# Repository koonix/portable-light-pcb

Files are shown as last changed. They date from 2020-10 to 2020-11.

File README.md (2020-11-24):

# Portable Light

This circuit is used in a battery-powered portable handy light source,
consisting of an array of LEDs, powered by a Panasonic lithium battery.

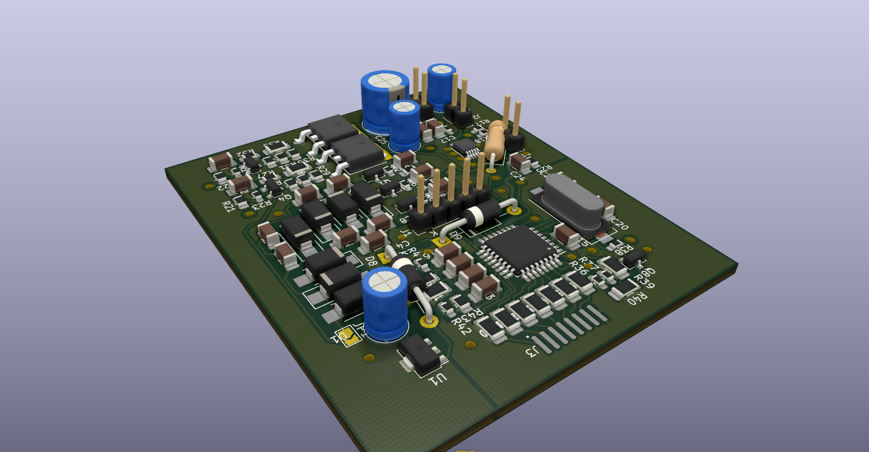
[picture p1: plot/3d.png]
3D Model of the old single-pcb version


## Modules

This circuit can be divided into these modules:

* [Control](#control-module)
* [Buck Converter](#buck-converter-module)
* [Charge Pump](#charge-pump-module)
* [Battery Charger](#battery-charger-module)

### Control Module

This module consists of the following:

* Microcontroller and it's driving components
* Shift register chip for driving the 7-Segment
* A 7-Segment and it's accompanying components

### Buck Converter Module

This module steps down the battery's voltage down to 3 Volts which is suitable
for the LEDs.

If battery voltage drops below 3 Volts however, this module is
turned off and the battery's voltage is directly passed through to the LEDs.

The signals required for control of the buck converter are provided by
the microcontroller.

### Charge Pump Module

The Control and Buck Converter modules require voltages upwards of 5 Volts
for their function, mainly needed by MOSFET's gates or the microcontroller
(When operating near 20MHz).

For that reason, this module consists of a 'Dickson charge pump' that converts
the 2.5v ~ 4.2v of the battery to 8v ~ 15v.

The signals required for driving the charge pump are provided by
the microcontroller.

### Battery Charger Module

Consisting of a LTC1733 Single-Cell Lithium Charge Controller, this module
takes care of topping off the battery when a charger is connected.

## More Detail

### How the 7-Segment is controlled/driven

A single CD4094 Shift-and-Store Register chip (similar to the infamous 595
Shift Register), Takes CLOCK, DATA, STROBE and OUTPUT-ENABLE signals from
the microcontroller and outputs the signals needed for controlling
the 7-Segment.

These signals are connected to bases of 7 PNP Transistors which drive the
LEDs of the 7-Segment directly.

### Control Module's input power

Taking advantage of two schottky diodes, power to the control
module will get sourced from either the battery or the charge pump (Which is
regulated down to 5 Volts.).

Because of the redundant-psu style dual-diode circuit, current will get sourced
from whichever source providing a higher voltage.

The diode accross Vout and Vin of the regulator is there to protect
the regulator if the Vout of the regulator goes higher than the Vin.
This shouldn't be much of a problem because of relatively small leakage
current of the dual-diode circuit, but is put there *'Just-in-Case™'*.

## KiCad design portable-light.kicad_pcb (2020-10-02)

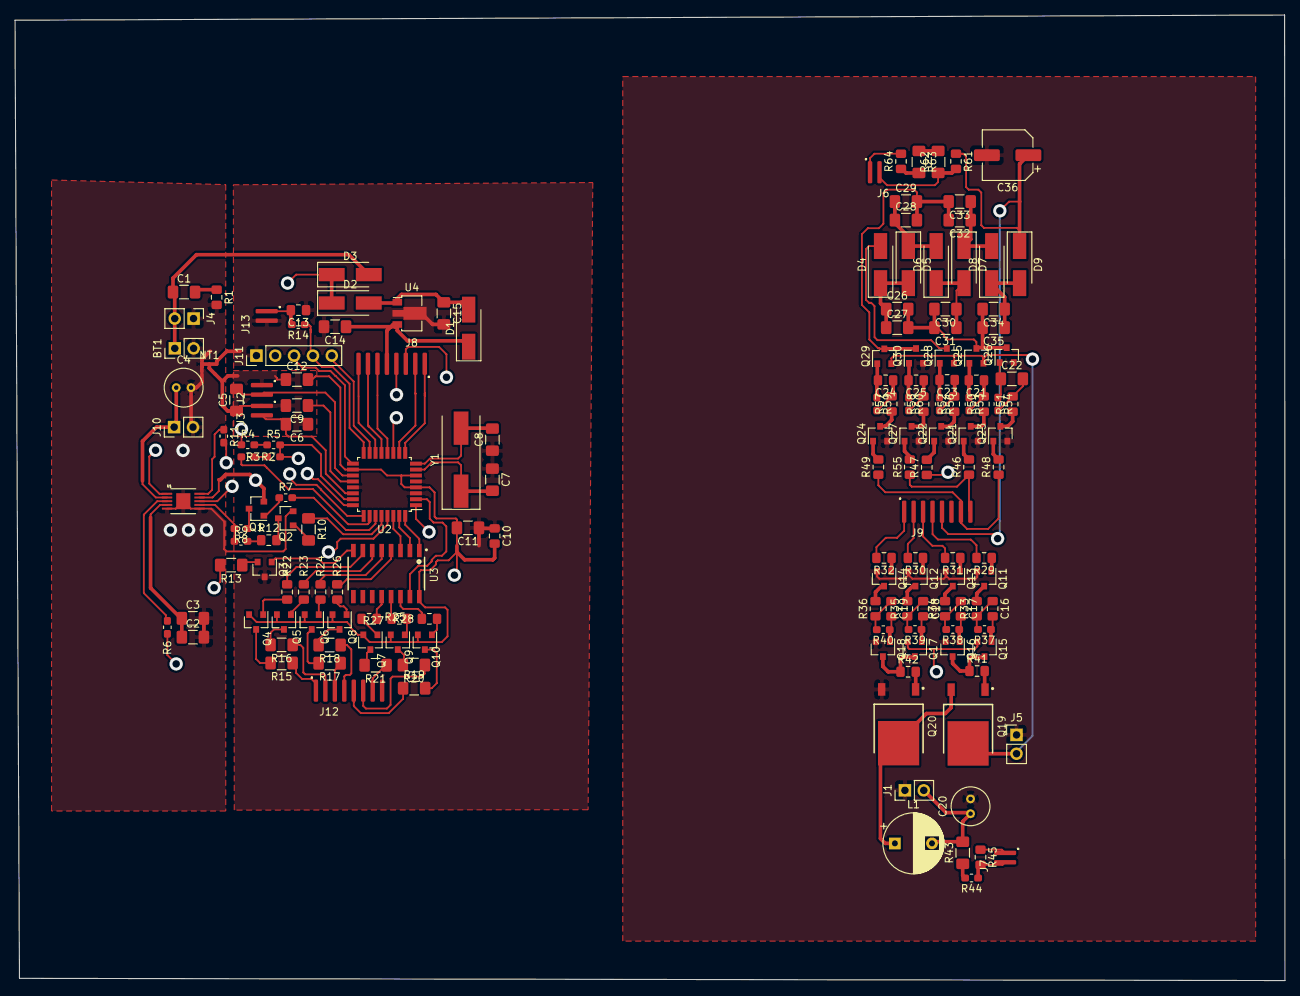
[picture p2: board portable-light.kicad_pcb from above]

Board: 10 copper layers, 171.2 x 130.2 mm, 160 parts (0 on the bottom side), 144 nets.

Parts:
BT1: Battery_Cell; PinHeader_1x02_P2.54mm_Vertical
C1, C26, C27, C28, C29, C30, C31, C32, C33, C34, C35: 330n; C_1206_3216Metric_Pad1.42x1.75mm_HandSolder
C2, C3, C9, C11, C12, C14, C15: 100n; C_1206_3216Metric_Pad1.42x1.75mm_HandSolder
C4, C20: 10u; C_Radial_D5.0mm_H7.0mm_P2.00mm
C5, C6: 15n; C_1206_3216Metric_Pad1.42x1.75mm_HandSolder
C7, C8: 22p; C_1206_3216Metric_Pad1.42x1.75mm_HandSolder
C10, C13: 300n; C_0805_2012Metric_Pad1.15x1.40mm_HandSolder
C16, C17, C18, C19, C21, C23, C24, C25: 10n; C_0805_2012Metric_Pad1.15x1.40mm_HandSolder
C22: 10n-big; C_1206_3216Metric_Pad1.42x1.75mm_HandSolder
C36: 100u; CP_Elec_6.3x5.9
D1: M7; D_SMA_Handsoldering
D2, D3, D4, D5, D6, D7, D8, D9: 1N5819; D_SMA_Handsoldering
J1: LOAD; PinHeader_1x02_P2.54mm_Vertical
J2: conn_sense_pump_2; Ribbon_2
J3: conn_sense_buck_2; Ribbon_2
J4: conn_batt_2; PinHeader_1x02_P2.54mm_Vertical
J5: conn_batt_1; PinHeader_1x02_P2.54mm_Vertical
J6: conn_sense_pump_1; Ribbon_2
J7: conn_sense_buck_1; Ribbon_2
J8: interboard-interface_2; Ribbon_8
J9: interboard-interface_1; Ribbon_8
J10: Charger; PinHeader_1x02_P2.54mm_Vertical
J11: Conn_01x05; PinHeader_1x05_P2.54mm_Vertical
J12: Conn_01x08; Ribbon_8
J13: Conn_01x02-Connector_Generic; Ribbon_2
L1: 22u; CP_Radial_D8.0mm_P5.00mm
NT1: Net-Tie_3_Tee; NetTie-3_SMD_Pad0.5mm
Q1, Q4, Q5, Q6, Q7, Q8, Q9, Q10, Q15, Q17: Q_PNP_BCE; SOT-23
Q2: MMBT2222A; SOT-23
Q3: Q_NMOS_DGS; SOT-23
Q11, Q12, Q13, Q14, Q16, Q18, Q21, Q22, Q23, Q24, Q26, Q27, Q30: MMBT2222; SOT-23
Q19, Q20: PHD45N03LTA; DPAK
Q25, Q28, Q29: S9012; SOT-23
R1: 1R60; R_0805_2012Metric_Pad1.15x1.40mm_HandSolder
R2, R3, R6, R8, R9, R11, R14, R37, R38, R39, R40, R44, R53, R54, R56, R59, R60: 1K; R_0603_1608Metric_Pad1.05x0.95mm_HandSolder
R4: 150K; R_0603_1608Metric_Pad1.05x0.95mm_HandSolder
R5: 270K; R_0603_1608Metric_Pad1.05x0.95mm_HandSolder
R7: 10K; R_0603_1608Metric_Pad1.05x0.95mm_HandSolder
R10, R13: 10K; R_1206_3216Metric_Pad1.42x1.75mm_HandSolder
R12: 510R; R_0805_2012Metric_Pad1.15x1.40mm_HandSolder
R15, R16, R17, R18, R19, R20, R21, R43: 475R; R_1206_3216Metric_Pad1.42x1.75mm_HandSolder
R22, R23, R24, R25, R26, R27, R28: 5K1; C_0805_2012Metric_Pad1.15x1.40mm_HandSolder
R29, R30, R31, R32: 10K; R_0805_2012Metric_Pad1.15x1.40mm_HandSolder
R33, R34, R35, R36: 56R; R_0805_2012Metric_Pad1.15x1.40mm_HandSolder
R41, R42: 33R; R_0805_2012Metric_Pad1.15x1.40mm_HandSolder
R45: 475R; R_0805_2012Metric_Pad1.15x1.40mm_HandSolder
R46, R47, R48, R49, R55, R61: 10K; C_0805_2012Metric_Pad1.15x1.40mm_HandSolder
R50, R51, R52, R57, R58, R64: 56R; C_0805_2012Metric_Pad1.15x1.40mm_HandSolder
R62: 475R; C_1206_3216Metric_Pad1.42x1.75mm_HandSolder
R63: 140R; C_1206_3216Metric_Pad1.42x1.75mm_HandSolder
U1: LTC1733EMSEPBF; MSOP-10_MSE
U2: ATmega88PA-AU; TQFP-32_7x7mm_P0.8mm
U3: CD4094BPW; SOP-16
U4: L78L05_SOT89; SOT-89-3
Y1: 20MHz Crystal; Crystal_SMD_HC49-SD

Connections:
+5V: C10.2, C11.2, C12.2, D2.1, D3.1, Q4.2, Q5.2, Q6.2, Q7.2, Q8.2, Q9.2, Q10.2, R4.1, U2.4, U2.6, U2.18, U3.16
+BATT-1: J5.2, Q19.4, Q25.2, Q28.2, Q29.2
+BATT-2: BT1.1, C1.1, D3.2, J4.2, Q1.2, U1.9
+CHARGER: C4.1, J10.1, U1.2, U1.8
+PUMP-1: C36.1, D9.1, J9.5, Q15.2, Q17.2, R61.1
+PUMP-2: C14.1, D1.1, J8.5, U4.3
/Buck converter/vout: C20.1, J1.2, L1.2, R43.2
/Charger/acpr_out: R11.2, U2.25
/Controller/button: C13.2, J13.1, R14.2
/Controller/charger_chrg_in: R3.2, R5.2, U1.1, U2.23
/Controller/charger_chrg_pulldown_or_float_out: R2.1, U2.26
/Controller/charger_fault_in: R6.1, U2.24
/Controller/charger_prog_disable_charging: R10.1, U2.28
/Controller/charger_prog_enable_charging: R7.2, U2.27
/Controller/miso: J11.4, R14.1, U2.16
/Controller/reset: J11.2, U2.29
/Controller/sck: J11.3, U2.17
/Controller/seg-1: Q4.3, R15.2
/Controller/seg-2: Q5.3, R16.2
/Controller/seg-3: Q6.3, R17.2
/Controller/seg-4: Q8.3, R18.2
/Controller/seg-5: Q10.3, R19.2
/Controller/seg-6: Q9.3, R20.2
/Controller/seg-7: Q7.3, R21.2
/Controller/seg-base-1: R26.2, U3.4
/Controller/seg-base-2: R24.2, U3.5
/Controller/seg-base-3: R23.2, U3.6
/Controller/seg-base-4: R22.2, U3.7
/Controller/seg-base-5: R28.2, U3.14
/Controller/seg-base-6: R27.2, U3.13
/Controller/seg-base-7: R25.2, U3.12
/Controller/shiftregister-clock: U2.30, U3.3
/Controller/shiftregister-data: U2.31, U3.2
/Controller/shiftregister-enable: U2.2, U3.15
/Controller/shiftregister-strobe: U2.32, U3.1
/Controller/shiftregister-vss: R13.2, U2.11
/Controller/xtal1: C7.2, U2.7, Y1.1
/Controller/xtal2: C8.2, U2.8, Y1.2
/buck_high_mos_high_bjt_1: J9.4, R29.2
/buck_high_mos_high_bjt_2: J8.4, U2.1
/buck_high_mos_low_bjt_1: J9.3, R31.2
/buck_high_mos_low_bjt_2: J8.3, J11.5, U2.15
/buck_low_mos_high_bjt_1: J9.2, R30.2
/buck_low_mos_high_bjt_2: J8.1, U2.9
/buck_low_mos_low_bjt_1: J9.1, R32.2
/buck_low_mos_low_bjt_2: J8.2, U2.10
/gnd_vsense_buck_1: J7.1, R45.1
/gnd_vsense_pump_1: J6.1, R64.2
/pump_clka_1: J9.8, R46.1, R55.1
/pump_clka_2: J8.7, U2.13
/pump_clkb_1: J9.7, R48.1, R49.1
/pump_clkb_2: J8.8, U2.14
/pump_onoff_1: J9.6, R47.1
/pump_onoff_2: J8.6, U2.12
/vsense_buck_1: J7.2, R44.1, R45.2
/vsense_buck_2: C6.2, J3.2, U2.22
/vsense_pump_1: J6.2, R61.2, R62.1
/vsense_pump_2: C5.2, J2.2, U2.19
GND: C7.1, C8.1, C10.1, C11.1, C13.1, C14.2, C15.2, J11.1, J12.8, J13.2, NT1.3, Q3.3, U2.3, U2.5, U2.21, U4.2
GND-CHARGER: BT1.2, C2.2, C3.2, C4.2, J4.1, J10.2, NT1.1, Q2.2, R1.2, U1.5, U1.6, U1.11
GNDA: C5.1, C6.1, C9.2, C12.1, J2.1, J3.1, NT1.2
GNDPWR: C20.2, C36.2, J1.1, J5.1, Q11.2, Q12.2, Q13.2, Q14.2, Q16.2, Q18.2, Q20.3, Q21.2, Q22.2, Q23.2, Q24.2, Q26.2, Q27.2, Q30.2
unnamed: C1.2, R1.1
unnamed: C2.1, C3.1, U1.4
unnamed: C9.1, U2.20
unnamed: C15.1, D1.2, D2.2, U4.1
unnamed: C16.1, R33.1, R37.2
unnamed: C16.2, Q15.1, R37.1
unnamed: C17.1, R34.1, R38.2
unnamed: C17.2, Q16.1, R38.1
unnamed: C18.1, R35.1, R39.2
unnamed: C18.2, Q17.1, R39.1
unnamed: C19.1, R36.1, R40.2
unnamed: C19.2, Q18.1, R40.1
unnamed: C21.1, R50.2, R53.2
unnamed: C21.2, Q25.1, R53.1
unnamed: C22.1, Q26.1, R54.1
unnamed: C22.2, R51.2, R54.2
unnamed: C23.1, R52.2, R56.2
unnamed: C23.2, Q28.1, R56.1
unnamed: C24.1, R57.2, R59.2
unnamed: C24.2, Q29.1, R59.1
unnamed: C25.1, R58.2, R60.2
unnamed: C25.2, Q30.1, R60.1
unnamed: C26.1, C27.1, D4.1, D5.2
unnamed: C26.2, C27.2, C30.2, C31.2, C34.2, C35.2, Q25.3, Q26.3
unnamed: C28.1, C29.1, D5.1, D6.2
unnamed: C28.2, C29.2, C32.2, C33.2, Q29.3, Q30.3
unnamed: C30.1, C31.1, D6.1, D7.2
unnamed: C32.1, C33.1, D7.1, D8.2
unnamed: C34.1, C35.1, D8.1, D9.2
unnamed: D4.2, Q28.3
unnamed: J12.1, R15.1
unnamed: J12.2, R16.1
unnamed: J12.3, R17.1
unnamed: J12.4, R18.1
unnamed: J12.5, R19.1
unnamed: J12.6, R20.1
unnamed: J12.7, R21.1
unnamed: L1.1, Q19.3, Q20.4
unnamed: Q1.1, R7.1
unnamed: Q1.3, R8.1
unnamed: Q2.1, R10.2
unnamed: Q2.3, R12.2
unnamed: Q3.1, U3.8
unnamed: Q3.2, R13.1
unnamed: Q4.1, R22.1
unnamed: Q5.1, R23.1
unnamed: Q6.1, R24.1
unnamed: Q7.1, R25.1
unnamed: Q8.1, R26.1
unnamed: Q9.1, R27.1
unnamed: Q10.1, R28.1
unnamed: Q11.1, R29.1
unnamed: Q11.3, R33.2
unnamed: Q12.1, R30.1
unnamed: Q12.3, R35.2
unnamed: Q13.1, R31.1
unnamed: Q13.3, R34.2
unnamed: Q14.1, R32.1
unnamed: Q14.3, R36.2
unnamed: Q15.3, Q16.3, R41.1
unnamed: Q17.3, Q18.3, R42.1
unnamed: Q19.1, R41.2
unnamed: Q20.1, R42.2
unnamed: Q21.1, R46.2
unnamed: Q21.3, R50.1
unnamed: Q22.1, R47.2
unnamed: Q22.3, R52.1
unnamed: Q23.1, R48.2
unnamed: Q23.3, R51.1
unnamed: Q24.1, R49.2
unnamed: Q24.3, R57.1
unnamed: Q27.1, R55.2
unnamed: Q27.3, R58.1
unnamed: R2.2, R3.1
unnamed: R4.2, R5.1
unnamed: R6.2, U1.3
unnamed: R8.2, R9.1, U1.7
unnamed: R11.1, U1.10
unnamed: R9.2, R12.1
unnamed: R43.1, R44.2
unnamed: R62.2, R63.1
unnamed: R63.2, R64.1

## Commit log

2020-07-23 Schematics and PCB layout complete
    [portable-light.kicad_pcb, portable-light.sch]
2020-07-24 commit before checkout
    [portable-light.kicad_pcb, portable-light.sch]
2020-07-24 LTC1733 bug fixed
    [portable-light.kicad_pcb]
2020-07-24 AVR Charge-pump bug fixed
    [portable-light.kicad_pcb, portable-light.sch]
2020-07-25 Added push-button
    [portable-light.kicad_pcb, portable-light.sch]
2020-07-25 First review and refactoring complete; PCB is ready
    [portable-light.kicad_pcb, portable-light.sch]
2020-08-10 divided schematics into multiple sheets moved to arch
    [pl-buckconverter.sch, pl-chargepump.sch, pl-charger.sch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]
2020-08-29 Fixed hierarchical sheet for microcontroller unit
    [pl-buckconverter.sch, pl-chargepump.sch, pl-charger.sch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]
2020-08-29 Charger hierarchical sheet fixed
    [pl-chargepump.sch, pl-charger.sch, portable-light.sch]
2020-09-06 Schematic's overall structure is finished
    [pl-buck_converter.sch, pl-buckconverter.sch, pl-charge_pump.sch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]
2020-09-12 Added component values
    [pl-buck_converter.sch, pl-charge_pump.sch, pl-charger.sch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]
2020-09-25 Schematics redesigned and fixed
    [pl-buck_converter.sch, pl-charge_pump.sch, pl-charger.sch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]
2020-09-25 Updated pcb from schem
    [portable-light.kicad_pcb]
2020-09-27 Cleaned up the PCB a little bit, Fixed some errors in schematics
    [pl-controller.sch, portable-light.kicad_pcb, portable-light.sch]
2020-09-27 Fixed some minor stuff in schematics, Refined the PCB a little bit more
    [pl-controller.sch, portable-light.kicad_pcb]
2020-10-02 Seperated the two PCBs successfully, All DRC errors fixed, gotta double check the circuit
    [pl-buck_converter.sch, pl-charge_pump.sch, pl-charger.sch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]
